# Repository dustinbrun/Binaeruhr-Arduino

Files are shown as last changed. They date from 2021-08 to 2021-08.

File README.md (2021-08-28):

# Arduino Binäruhr 
Eine Binäruhr basierend auf einem Arduino Nano. Die LEDs werden mit Hilfe von 74HC595 Schieberegistern angesteuert.

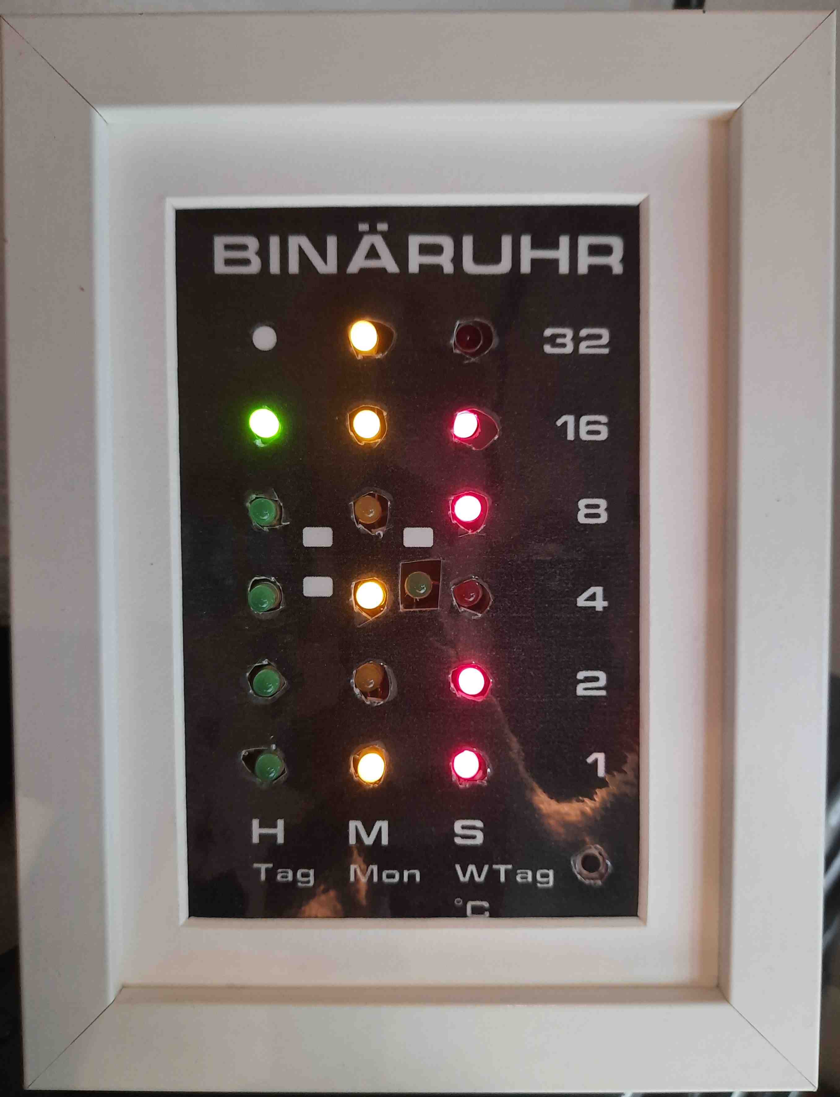
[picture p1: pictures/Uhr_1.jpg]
[](pictures/Uhr_1.jpg)
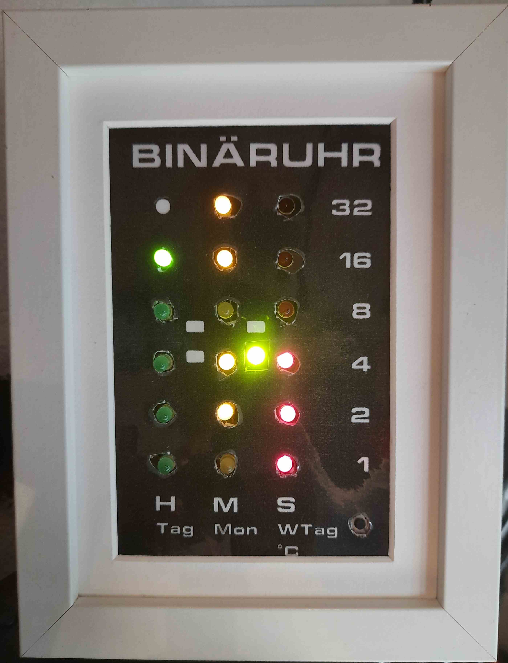
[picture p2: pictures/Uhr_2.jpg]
[](pictures/Uhr_2.jpg)
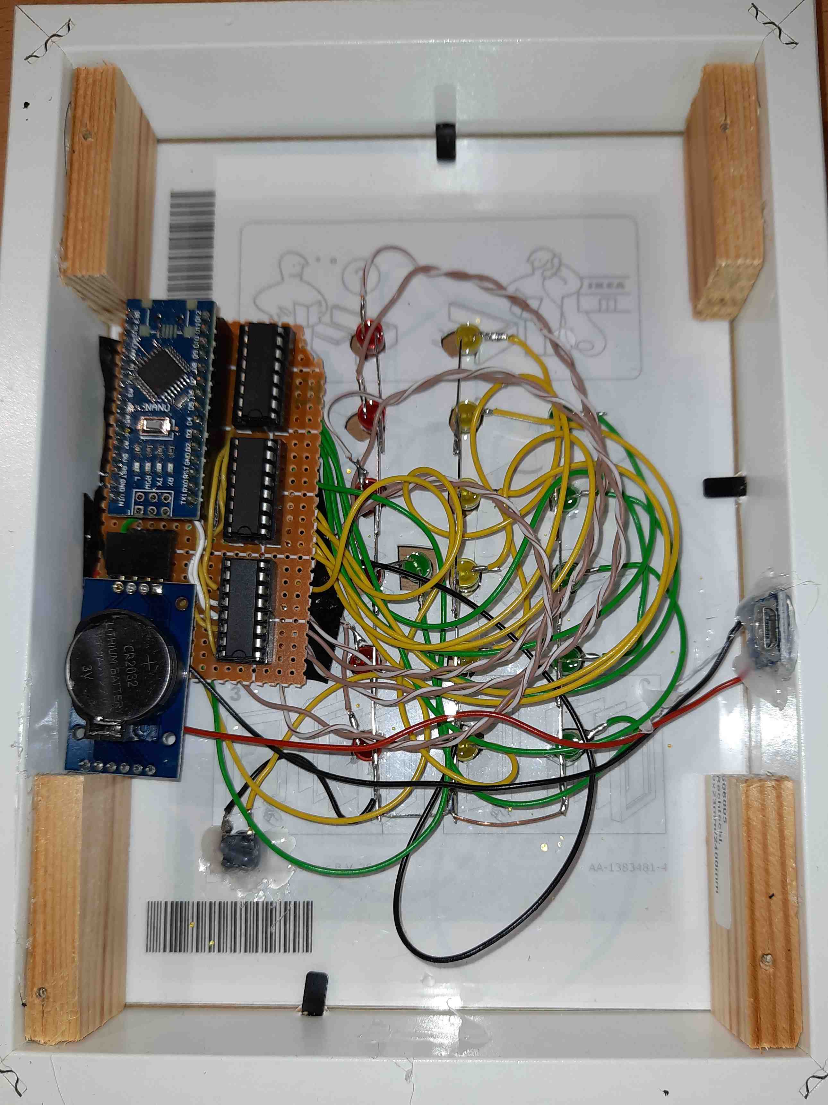
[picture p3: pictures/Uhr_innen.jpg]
[](pictures/Uhr_innen.jpg)

## Features
- Einbau in einem IKEA Ribba Bilderrahmen 13x18 cm (bzw. 10x15 cm)
- Die Zeit wird von einer DS3231 RTC bereitgestellt
- Ein Taster zum ändern der Anzeige:
  - Normalmodus: Zeitanzeige - Stunden, Minuten, Sekunden
  - Datumsanzeige - Tag, Monat, Tag der Woche (1-7)
  - Temperaturanzeige - Temperaturmessung erfolgt durch das RTC-Modul 
    - Wenn die Anzeige im Datum- oder Temperaturmodus ist, wechselt sie nach 10 Sekunden automatisch zum Normalmodus zurück
- Eine extra LED blinkt 2 mal jede Sekunde

# Hardware
## Schaltplan
**Im Schaltplan sind keine Vorwiderstände für die einzelnen LEDs eingetragen, diese sollten jedoch verbaut werden! (Wert: 220R)** <br><br>
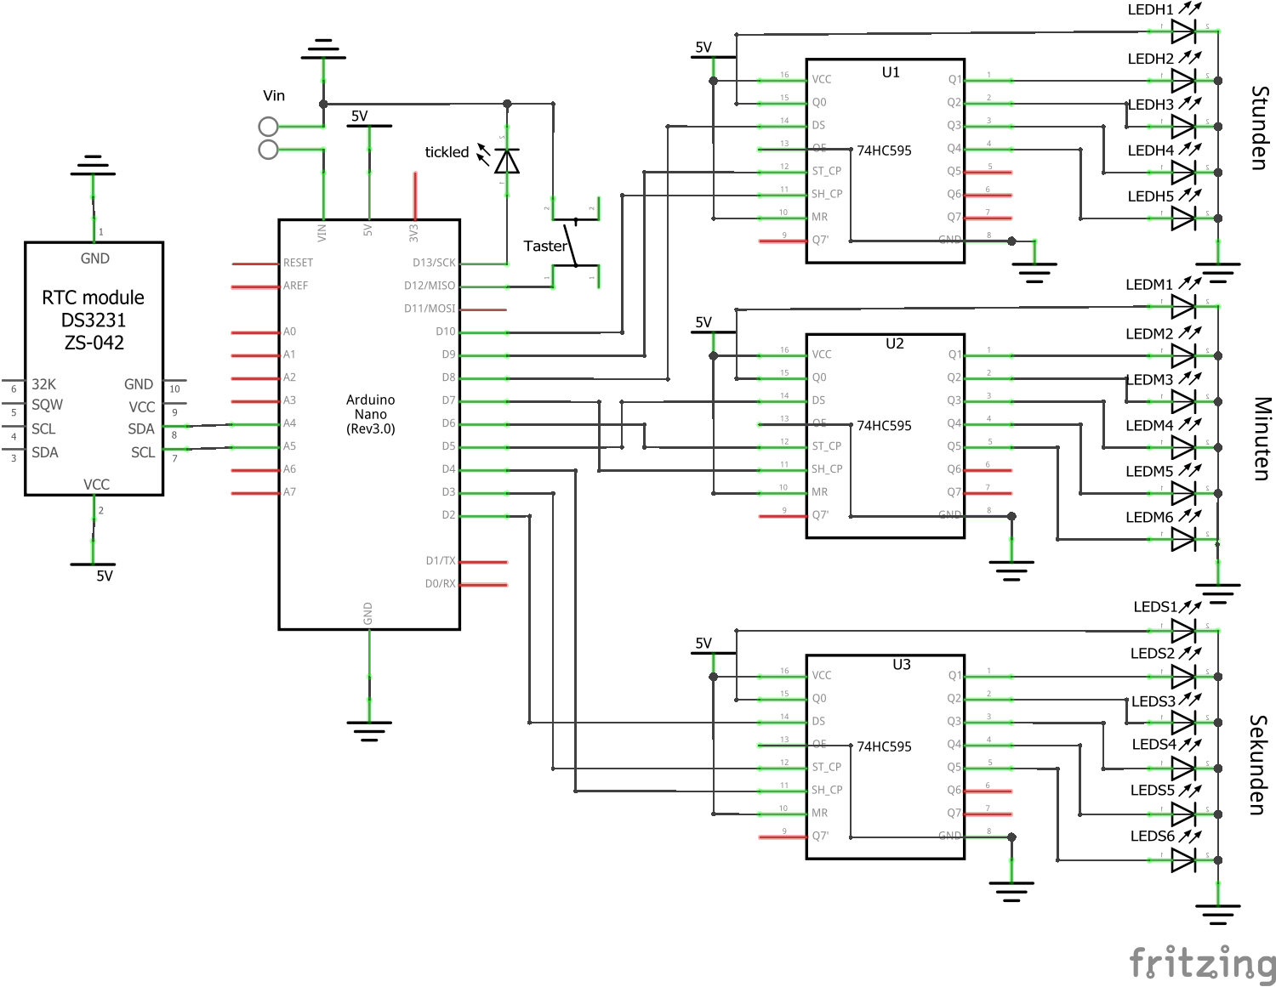
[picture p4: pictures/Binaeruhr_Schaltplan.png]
[](pictures/Binaeruhr_Schaltplan.png)

## Leiterplatte
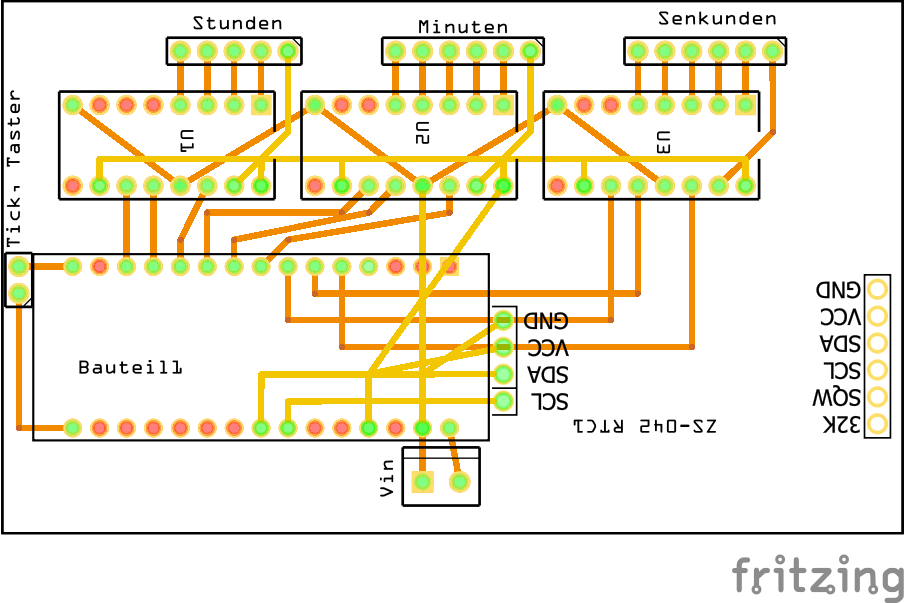
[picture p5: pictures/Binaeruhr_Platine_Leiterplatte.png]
[](pictures/Binaeruhr_Platine_Leiterplatte.png)

## Frontplatte
Ich habe für den Bilderrahmen eine Frontplatte erstellt (Software: Frontplatten Designer, Schaeffer AG). Diese ist passend für den IKEA Bilderrahmen und kann im Format **10x15 cm** ausgeruckt werden. 
<br><br>
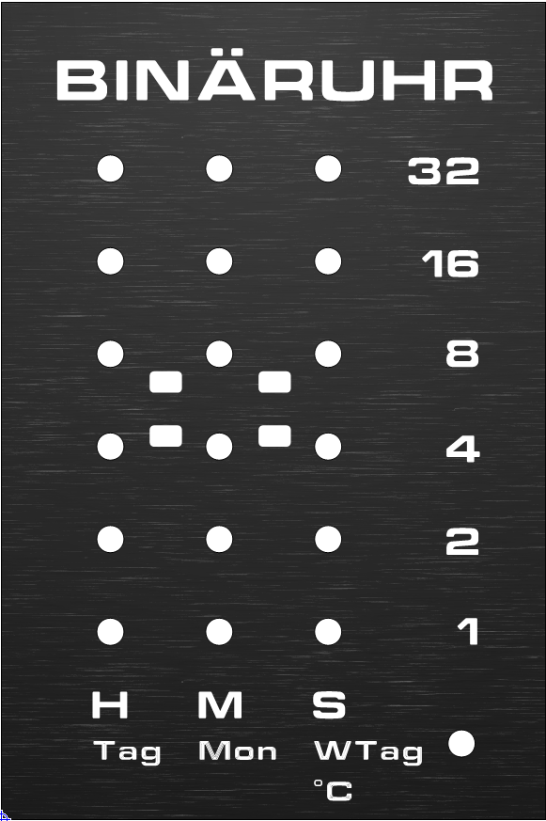
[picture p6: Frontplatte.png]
[](Frontplatte.png)

# Software
Der Code kann ohne weitere Änderungen verwendet werden. Um die Zeit des RTC-Moduls einzustellen müssen im Code die entsprechenden Zeilen auskommentiert und mit der aktuellen Uhrzeit gefüllt werden. Anschließend muss dieser Code **einmalig** auf dem Arduino ausgeführt werden.

Die Verwendete Bibiliothek für die DS3231 ist im Ordner des Programmes bereits hinterlegt und muss nicht extra heruntergeladen werden. Zusätzlich ist die Quelle der Bibiliothek jedoch im Code verlinkt.

# Quellen
- https://pascalstechtips.weebly.com/projekte/arduino-binruhr-v10 
- DS3231: http://www.rinkydinkelectronics.com/library.php?id=73
- Software für Frontplatte: https://www.schaeffer-ag.de/frontplatten-designer#

<br><br>
<p xmlns:dct="http://purl.org/dc/terms/" xmlns:cc="http://creativecommons.org/ns#" class="license-text">This work by <span property="cc:attributionName">Dustin Brunner</span> is licensed under <a rel="license" href="https://creativecommons.org/licenses/by/4.0">CC BY 4.0</a></p>

<br />Dieses Werk von <span xmlns:cc="http://creativecommons.org/ns#" property="cc:attributionName">Dustin Brunner</span> ist lizenziert unter einer <a rel="license" href="http://creativecommons.org/licenses/by/4.0/">Creative Commons Namensnennung 4.0 International Lizenz</a>.

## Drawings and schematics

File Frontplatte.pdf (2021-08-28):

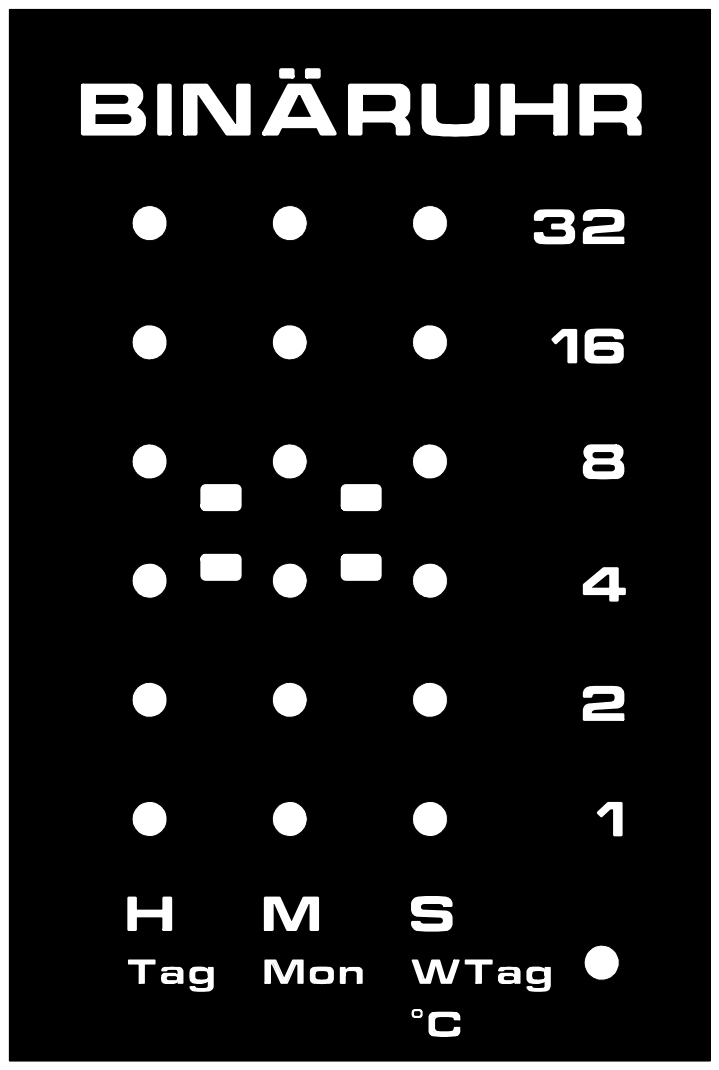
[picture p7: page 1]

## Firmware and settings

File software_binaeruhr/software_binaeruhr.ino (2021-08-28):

#include "src/DS3231.h" //http://www.rinkydinkelectronics.com/library.php?id=73

DS3231  rtc(SDA, SCL);

//Pins
//Pins für Sekunden-Schieberegister
const int clockPinS   = 4;
const int latchPinS   = 3;
const int dataPinS    = 2;
//Pins für Minuten-Schieberegister
const int clockPinM   = 7;
const int latchPinM   = 6;
const int dataPinM    = 5;
//Pins für Stunden-Schieberegister
const int clockPinH   = 10;
const int latchPinH   = 9;
const int dataPinH    = 8;

const int tickled = 13;
const int taster = 12;

//Variablen
long prevMillis = 0;
long interval   = 500;
Time t;
int stunden;
int minuten;
int sekunden;
int tag;
int monat;
int wochentag;
int temp;
int halbesekunde = 0;
int modus = 1;
int modustimer = 0;

void setup(){
  //Outputpins
  pinMode(clockPinS, OUTPUT);
  pinMode(dataPinS,  OUTPUT);
  pinMode(latchPinS, OUTPUT);
  pinMode(clockPinM, OUTPUT);
  pinMode(dataPinM,  OUTPUT);
  pinMode(latchPinM, OUTPUT);
  pinMode(clockPinH, OUTPUT);
  pinMode(dataPinH,  OUTPUT);
  pinMode(latchPinH, OUTPUT);
  pinMode(tickled, OUTPUT);
  
  //Inputpin
  pinMode(taster, INPUT_PULLUP);
  
  //RTC
  rtc.begin();
  
  // Nachfolgende Linien zur Zeiteinstellung unkommentieren
  //rtc.setDOW(2);                // Wochentag einstellen -> 1=Montag, 2=Dienstag, ...
  //rtc.setTime(16, 58, 00);     // Uhrzeit einstellen (Stunde, Minute, Sekunde)
  //rtc.setDate(02, 04, 2019);   // Datum einstellen (Tag, Monat, Jahr)

  
  //für Debugging un-kommentieren
  //Serial.begin(9600);
} //Ende von setup()

void loop(){
  /*if (digitalRead(addhour) == LOW){ //falls Minuten erhöht werden sollen
    delay(100);
    minutes += 1;
    if (minutes > 58){
      minutes = 0;
    }
    Serial.println("Minute++");
    while(digitalRead(2) == LOW){
      delay(10);
      }
  }*/

  if (digitalRead(taster) == LOW){
    modus++;
    modustimer = 0;
    if (modus == 4){
      modus = 1;
    }
    while(digitalRead(taster) == LOW){}
    delay(100);
  }

  if(modustimer >= 10){
    modus = 1;
    modustimer = 0;
  }
     
   unsigned long currentMillis = millis();
   if (currentMillis - prevMillis > interval) {
     prevMillis = currentMillis;

     if(halbesekunde == 1){
       if (modus == 1){
        t = rtc.getTime();
        stunden = t.hour, DEC;
        minuten = t.min, DEC;
        sekunden = t.sec, DEC;
        digitalWrite(tickled, HIGH);
        displayTime();
       }
       else if (modus == 2){
        t = rtc.getTime();
        tag = t.date, DEC;
        monat = t.mon, DEC;
        wochentag = t.dow, DEC;
        modustimer++;
        displayDate();
       }
       else if (modus == 3){
        temp = int(rtc.getTemp());
        modustimer++;
        displayTemp();
       }
       
       //für Debugging un-kommentieren
       /*Serial.println("");
       Serial.println("Zeit:"); //für debugging
       Serial.print(String(stunden));
       Serial.print(":");
       Serial.print(String(minuten));
       Serial.print(":");
       Serial.print(String(sekunden));
       //*/
       
       halbesekunde = 0;
     }
     else{
       digitalWrite(tickled, LOW);
       halbesekunde = 1;
     }
   }
   
} //Ende von loop()


void displayTime(){ //Sendet die Zeit zu den Shiftregistern
    //Sekunden
    digitalWrite(latchPinS, LOW);
    shiftOut(dataPinS, clockPinS, MSBFIRST, sekunden);
    digitalWrite(latchPinS, HIGH);
    //Minuten
    digitalWrite(latchPinM, LOW);
    shiftOut(dataPinM, clockPinM, MSBFIRST, minuten);
    digitalWrite(latchPinM, HIGH);
    //Stunden
    digitalWrite(latchPinH, LOW);
    shiftOut(dataPinH, clockPinH, MSBFIRST, stunden);
    digitalWrite(latchPinH, HIGH);
}

void displayDate(){ //Sendet Datum zu den Shiftregistern
    digitalWrite(latchPinS, LOW);
    shiftOut(dataPinS, clockPinS, MSBFIRST, wochentag);
    digitalWrite(latchPinS, HIGH);
    digitalWrite(latchPinM, LOW);
    shiftOut(dataPinM, clockPinM, MSBFIRST, monat);
    digitalWrite(latchPinM, HIGH);
    digitalWrite(latchPinH, LOW);
    shiftOut(dataPinH, clockPinH, MSBFIRST, tag);
    digitalWrite(latchPinH, HIGH);
}

void displayTemp(){ //Sendet Temperatur zu den Shiftregistern
    digitalWrite(latchPinS, LOW);
    shiftOut(dataPinS, clockPinS, MSBFIRST, temp);
    digitalWrite(latchPinS, HIGH);
    digitalWrite(latchPinM, LOW);
    shiftOut(dataPinM, clockPinM, MSBFIRST, 0);
    digitalWrite(latchPinM, HIGH);
    digitalWrite(latchPinH, LOW);
    shiftOut(dataPinH, clockPinH, MSBFIRST, 0);
    digitalWrite(latchPinH, HIGH);
}
